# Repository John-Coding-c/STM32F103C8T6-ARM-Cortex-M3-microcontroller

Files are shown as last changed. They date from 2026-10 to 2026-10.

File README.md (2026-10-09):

# STM32 Demo PCB

STM32F103C8T6 breakout board — USB-powered, SWD/UART/I2C headers, 41 × 31 mm, 2 layers. KiCad 10.

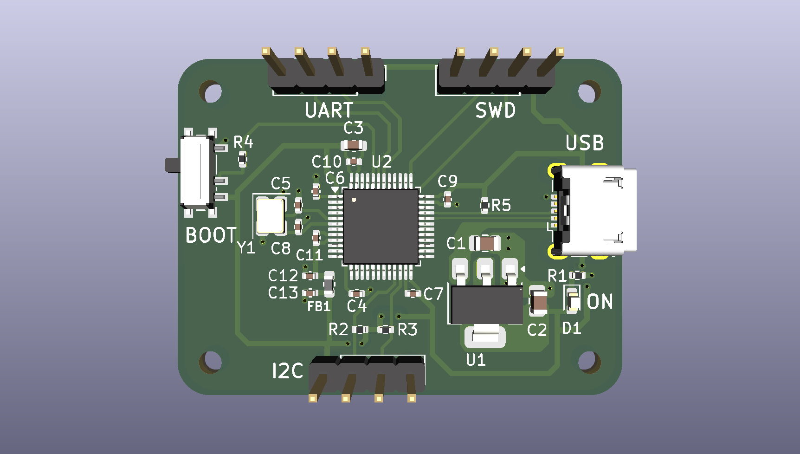
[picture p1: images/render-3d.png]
3D render


## Specs

- **MCU:** STM32F103C8T6, Cortex-M3 @ 72 MHz, 64 KB flash, 20 KB RAM, LQFP-48
- **Clock:** 16 MHz HSE crystal (3225), 2× 10 pF load caps
- **Power:** 5 V USB VBUS → AMS1117-3.3 LDO (1 A, SOT-223), 22 µF in/out
- **Decoupling:** 5× 100 nF (0402) + 10 µF bulk on VDD
- **VDDA:** filtered via 120 Ω ferrite bead + 10 nF + 1 µF
- **USB:** full-speed device on PA11/PA12, 1.5 kΩ D+ pull-up
- **Boot:** SPDT slide switch on BOOT0 via 10 kΩ
- **I2C pull-ups:** 1.5 kΩ to 3.3 V
- **Indicator:** red power LED (0603), 1.5 kΩ (~1 mA)
- **Mounting:** 4× 2.1 mm holes (M2), 3 mm corner radius

## Schematic

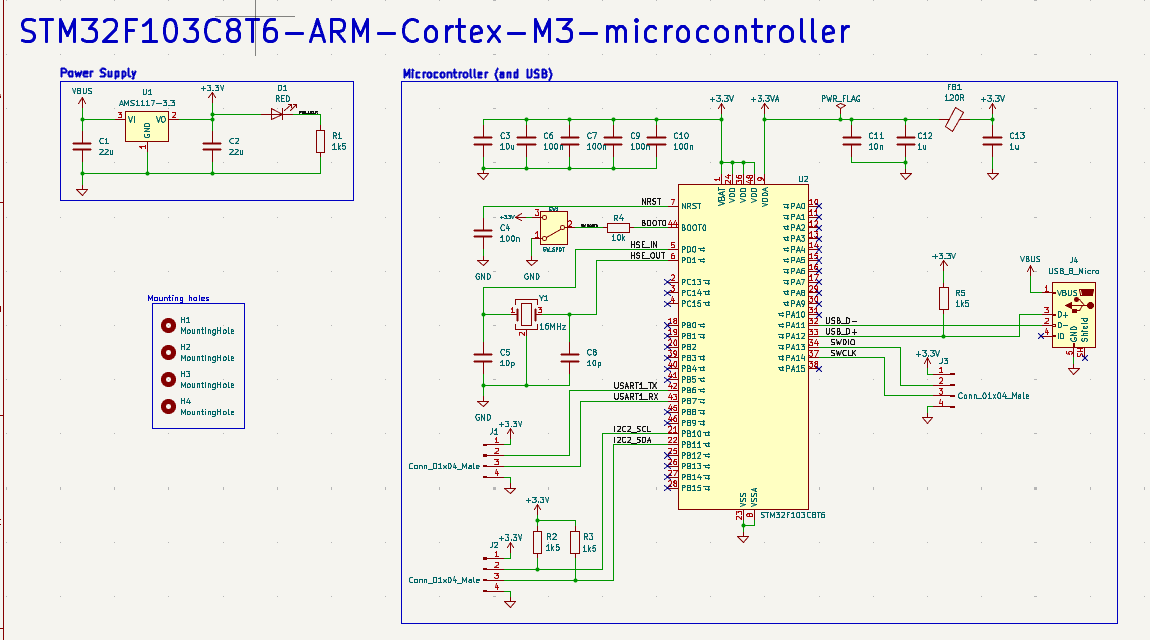
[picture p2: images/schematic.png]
Schematic


## PCB

| Parameter | Value |
| --- | --- |
| Size | 41 × 31 mm |
| Stackup | 2-layer, 1.6 mm FR4, 35 µm Cu |
| Bottom layer | Solid GND pour |
| Min track / clearance | 0.2 / 0.2 mm |
| Power tracks | 0.5 mm |
| Vias | 0.6–0.7 mm / 0.3 mm drill |
| Components | 28 parts + 4 mounting holes, all top side |
| Passives | 0402 / 0603 / 0805 |

## Pinout

All headers 1×4, 2.54 mm. Pin 1 = square pad.

| Header | Pin 1 | Pin 2 | Pin 3 | Pin 4 |
| --- | --- | --- | --- | --- |
| SWD (J3) | 3.3 V | SWDIO / PA13 | SWCLK / PA14 | GND |
| UART (J1) | 3.3 V | TX / PB6 | RX / PB7 | GND |
| I2C (J2) | 3.3 V | SCL / PB10 | SDA / PB11 | GND |

- UART uses remapped USART1 — set `AFIO_MAPR_USART1_REMAP` in firmware.

## BOM

| Ref | Qty | Value | Package |
| --- | --- | --- | --- |
| U2 | 1 | STM32F103C8T6 | LQFP-48 |
| U1 | 1 | AMS1117-3.3 | SOT-223 |
| Y1 | 1 | 16 MHz | 3225-4 |
| J4 | 1 | Micro-USB B (Würth 629105150521) | SMD |
| J1–J3 | 3 | 1×4 header | 2.54 mm THT |
| SW1 | 1 | SPDT slide (C&K PCM12) | SMD |
| D1 | 1 | Red LED | 0603 |
| FB1 | 1 | 120 Ω ferrite | 0603 |
| C1, C2 | 2 | 22 µF | 0805 |
| C3 | 1 | 10 µF | 0603 |
| C4, C6, C7, C9, C10 | 5 | 100 nF | 0402 |
| C5, C8 | 2 | 10 pF | 0402 |
| C11 | 1 | 10 nF | 0402 |
| C12, C13 | 2 | 1 µF | 0402 |
| R1–R3, R5 | 4 | 1.5 kΩ | 0402 |
| R4 | 1 | 10 kΩ | 0402 |

- LCSC part numbers included — ready for JLCPCB assembly.
- Full files: `STM32-BOM.csv`, `STM32-all-pos.csv`

## Files

```
STM32.kicad_pro / .kicad_sch / .kicad_pcb   KiCad project
STM32-BOM.csv, STM32-all-pos.csv            BOM + pick-and-place
629105150521 (rev1).stp                     USB connector 3D model
manufracture/                               Gerbers + drill
images/                                     Render + schematic
```

## Programming

- **SWD:** ST-Link V2 → J3. Flash with STM32CubeProgrammer or OpenOCD.
- **Bootloader:** BOOT0 = 1 enters the ROM bootloader, but it listens on PA9/PA10, which are not broken out — use SWD.

## Known Issues / Rev 0.2

- No ESD protection or fuse on USB VBUS
- USB shield unconnected
- No reset button

## License

[CERN-OHL-P-2.0](https://ohwr.org/cern_ohl_p_v2.txt) — permissive open hardware license. See `LICENSE`.

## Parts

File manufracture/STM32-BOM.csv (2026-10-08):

Reference | Qty | Value | DNP | Footprint | Datasheet
C1,C2 | 2 | 22u |  | Capacitor_SMD:C_0805_2012Metric
C3 | 1 | 10u |  | Capacitor_SMD:C_0603_1608Metric
C4,C6,C7,C9,C10 | 5 | 100n |  | Capacitor_SMD:C_0402_1005Metric
C5,C8 | 2 | 10p |  | Capacitor_SMD:C_0402_1005Metric
C11 | 1 | 10n |  | Capacitor_SMD:C_0402_1005Metric
C12,C13 | 2 | 1u |  | Capacitor_SMD:C_0402_1005Metric
D1 | 1 | RED |  | LED_SMD:LED_0603_1608Metric
FB1 | 1 | 120R |  | Inductor_SMD:L_0603_1608Metric
J1,J2,J3 | 3 | Conn_01x04_Male |  | Connector_PinHeader_2.54mm:PinHeader_1x04_P2.54mm_Vertical
J4 | 1 | USB_B_Micro |  | Connector_USB:USB_Micro-B_Wuerth_629105150521
R1,R2,R3,R5 | 4 | 1k5 |  | Resistor_SMD:R_0402_1005Metric
R4 | 1 | 10k |  | Resistor_SMD:R_0402_1005Metric
SW1 | 1 | SW_SPDT |  | Button_Switch_SMD:SW_SPDT_PCM12
U1 | 1 | AMS1117-3.3 |  | Package_TO_SOT_SMD:SOT-223-3_TabPin2 | http://www.advanced-monolithic.com/pdf/ds1117.pdf
U2 | 1 | STM32F103C8T6 |  | Package_QFP:LQFP-48_7x7mm_P0.5mm | https://www.st.com/resource/en/datasheet/stm32f103c8.pdf
Y1 | 1 | 16MHz |  | Crystal:Crystal_SMD_3225-4Pin_3.2x2.5mm

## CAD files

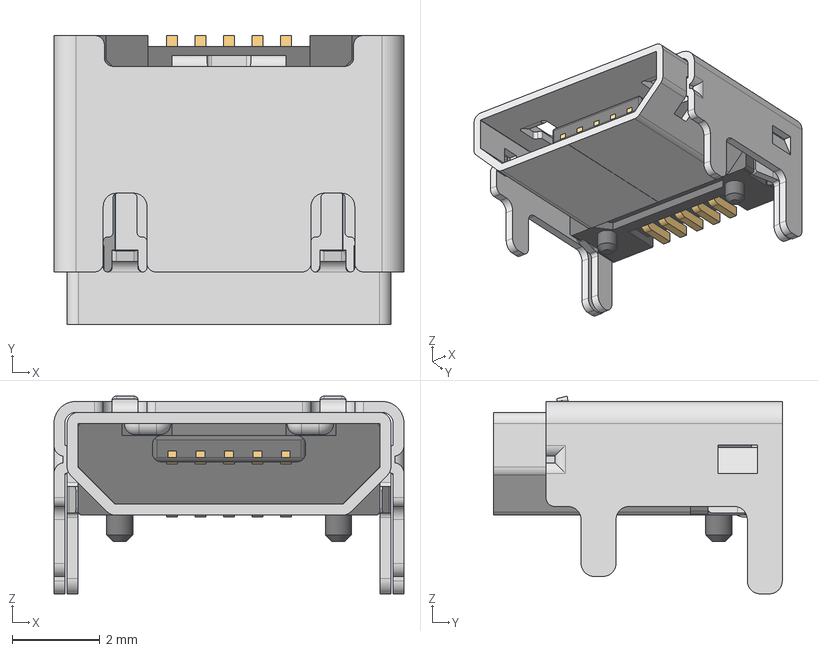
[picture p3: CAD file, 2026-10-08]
629105150521 (rev1).stp
8.00 x 6.60 x 4.52 mm
629105150521_Housing
629105150521_Pin1 x 4
629105150521_Pin2
629105150521_Shielding2
629105150521_Shielding

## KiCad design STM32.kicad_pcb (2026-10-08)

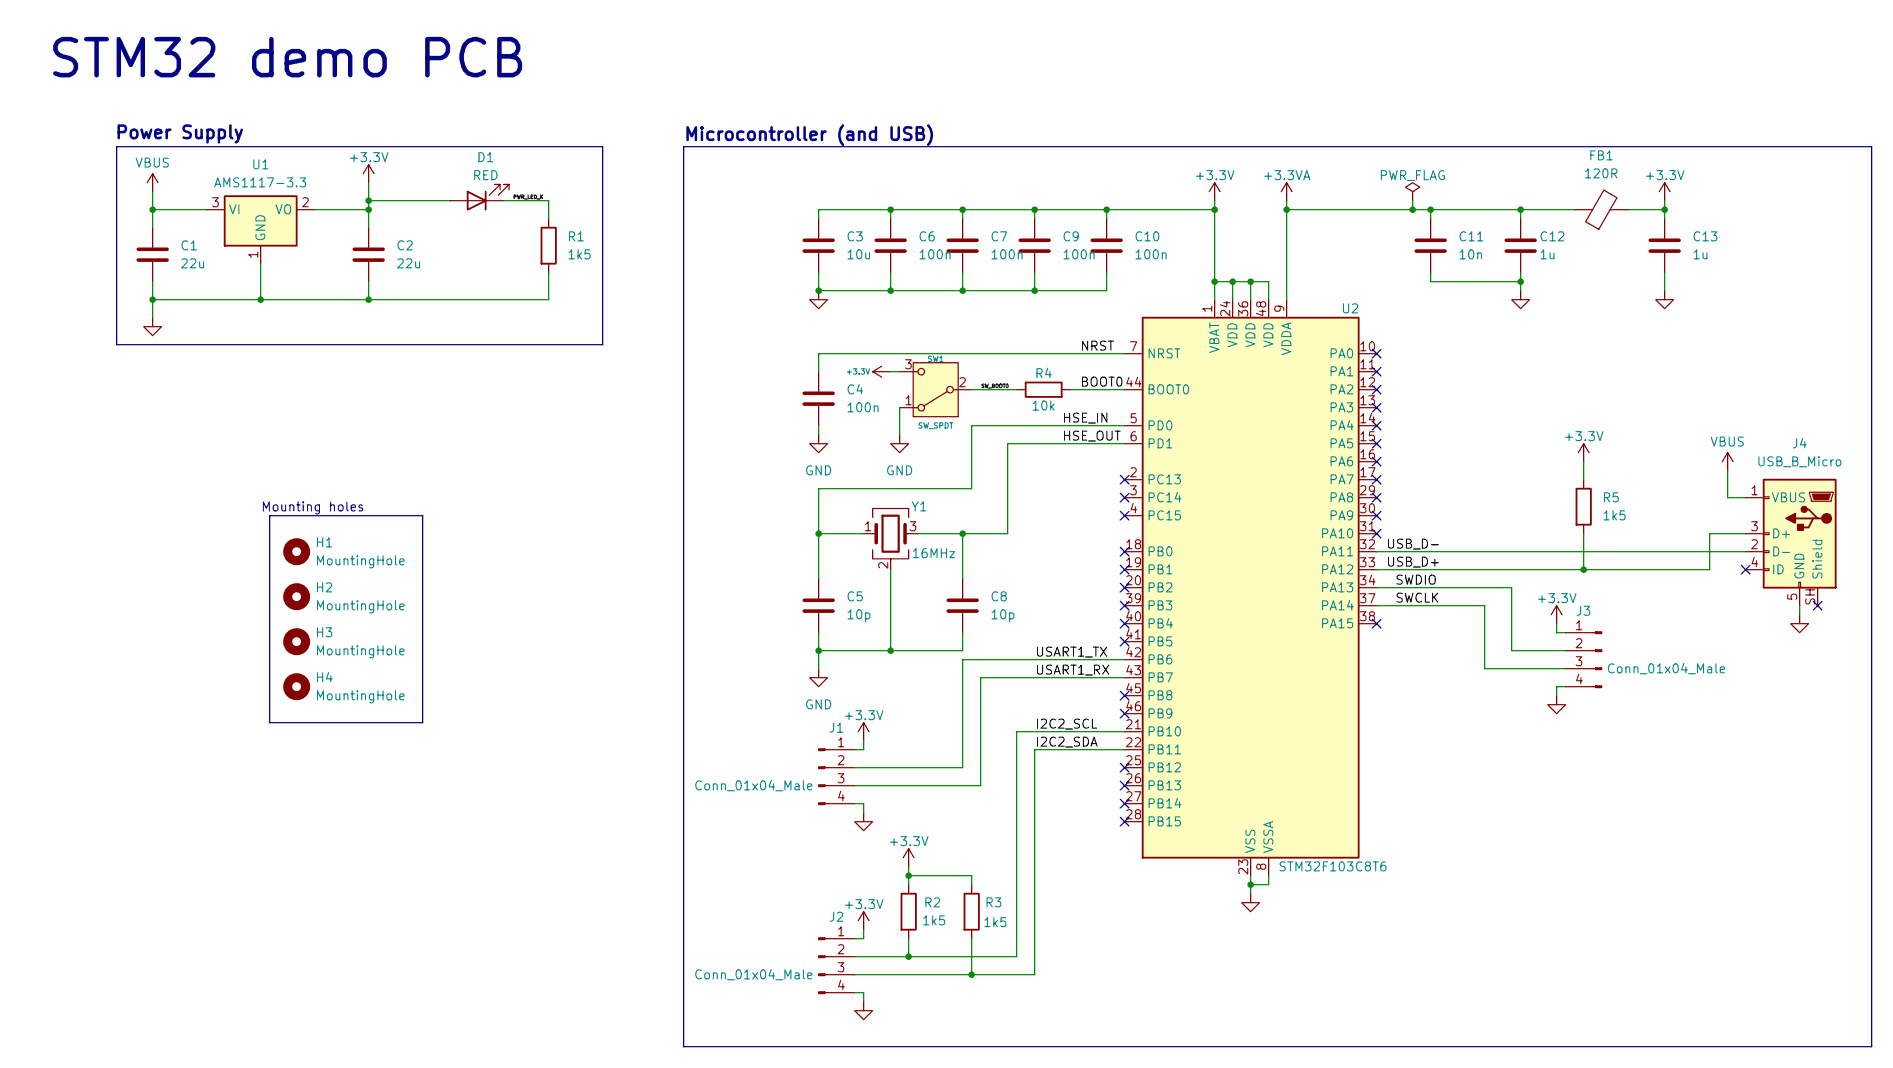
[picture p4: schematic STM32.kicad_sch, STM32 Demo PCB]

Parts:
C1, C2: 22u; C_0805_2012Metric; LCSC C45783
C3: 10u; C_0603_1608Metric; LCSC C19702
C4, C6, C7, C9, C10: 100n; C_0402_1005Metric; LCSC C1525
C5, C8: 10p; C_0402_1005Metric; LCSC C32949
C11: 10n; C_0402_1005Metric; LCSC C15195
C12, C13: 1u; C_0402_1005Metric; LCSC C52923
D1: RED; LED_0603_1608Metric; LCSC C2286
FB1: 120R; L_0603_1608Metric
H1, H2, H3, H4: MountingHole; MountingHole_2.1mm
J1, J2, J3: Conn_01x04_Male; PinHeader_1x04_P2.54mm_Vertical
J4: USB_B_Micro; USB_Micro-B_Wuerth_629105150521
R1, R2, R3, R5: 1k5; R_0402_1005Metric; LCSC C25867
R4: 10k; R_0402_1005Metric; LCSC C25744
SW1: SW_SPDT; SW_SPDT_PCM12; LCSC C221841
U1: AMS1117-3.3; SOT-223-3_TabPin2; LCSC C6186
U2: STM32F103C8T6; LQFP-48_7x7mm_P0.5mm; LCSC C8734
Y1: 16MHz; Crystal_SMD_3225-4Pin_3.2x2.5mm; LCSC C13738

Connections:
+3.3V: C2.1, C3.1, C6.1, C7.1, C9.1, C10.1, C13.1, D1.2 (A), FB1.2, J1.1, J2.1, J3.1, R2.1, R3.1, R5.1, SW1.3 (C), U1.2 (VO), U2.1 (VBAT), U2.24 (VDD), U2.36 (VDD), U2.48 (VDD)
+3.3VA: C11.1, C12.1, FB1.1, U2.9 (VDDA)
/BOOT0: R4.2, U2.44 (BOOT0)
/HSE_IN: C5.2, U2.5 (PD0), Y1.1
/HSE_OUT: C8.2, U2.6 (PD1), Y1.3
/I2C2_SCL: J2.2, R2.2, U2.21 (PB10)
/I2C2_SDA: J2.3, R3.2, U2.22 (PB11)
/NRST: C4.1, U2.7 (NRST)
/PWR_LED_K: D1.1 (K), R1.1
/SWCLK: J3.3, U2.37 (PA14)
/SWDIO: J3.2, U2.34 (PA13)
/SW_BOOT0: R4.1, SW1.2 (B)
/USART1_RX: J1.3, U2.43 (PB7)
/USART1_TX: J1.2, U2.42 (PB6)
/USB_D+: J4.3 (D+), R5.2, U2.33 (PA12)
/USB_D-: J4.2 (D-), U2.32 (PA11)
GND: C1.2, C2.2, C3.2, C4.2, C5.1, C6.2, C7.2, C8.1, C9.2, C10.2, C11.2, C12.2, C13.2, J1.4, J2.4, J3.4, J4.5 (GND), R1.2, SW1.1 (A), U1.1 (GND), U2.8 (VSSA), U2.23 (VSS), U2.35 (VSS), U2.47 (VSS), Y1.2 (G), Y1.4 (G)
VBUS: C1.1, J4.1 (VBUS), U1.3 (VI)

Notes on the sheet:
STM32 demo PCB
Mounting holes
Microcontroller (and USB)
Power Supply

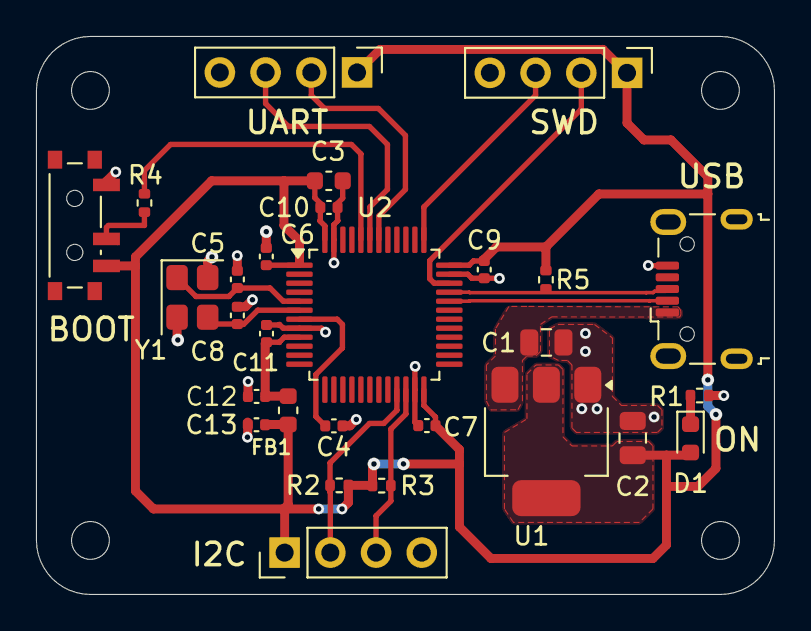
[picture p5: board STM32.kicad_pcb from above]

Board: 2 copper layers, 41.0 x 31.0 mm, 32 parts (0 on the bottom side), 18 nets.

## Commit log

2026-10-08 First board from a few months back, forgot to add to github, contains all the manufracturing files, BOM, ran ERC checks with no errors
    [629105150521 (rev1).stp, STM32-BOM.csv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]
2026-10-09 Add README
    Added detailed documentation for the STM32 Demo PCB including specifications, schematic, PCB layout, pinout, BOM, and programming instructions.
